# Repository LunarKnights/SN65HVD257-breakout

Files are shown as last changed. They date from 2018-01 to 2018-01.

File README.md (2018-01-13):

# Jetson CAN interface board
This board may be used to gain access to the CAN buses on the Jetson TX2 board, which aren't exposed on the carrier board we're currently using.
It mates in between the carrier board and the Jetson TX2, passing through all the connections, but tapping some lines off of the CAN pins and power supply to use in the SN65HVD256D CAN transceivers.
The CAN transceivers act essentially like level shifters, converting from the 3.3 V signals on the CAN RX/TX pins on the Jetson TX2 into the 5 V differential signal used in CAN.

`bom.xls` contains an Excel ordering list that should be usable at Mouser to reorder all the components except for the Samtec connectors.
Those need to be ordered off of the Samtec website, using the exact part names from the design.

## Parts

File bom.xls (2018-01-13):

SHOPPING CART
This is not an invoice
13-Jan-18 11:54:24
 | Mouser # | Mfr. # | Manufacturer | Customer # | Description | RoHS | Lifecycle | Order Qty. | Price (USD) | Ext.: (USD)
1 | 863-NCP7805TG | NCP7805TG | ON Semiconductor |  | Linear Voltage Regulators 1A LDO | RoHS Compliant |  | 5 | $0.43 | $2.15
2 | 538-39532-0002 | 39532-0002 | Molex |  | Pluggable Terminal Blocks 5.08MM EURO HEADER R EADER RA OE BLK 2CKT | RoHS Compliant |  | 5 | $0.50 | $2.50
3 | 538-39530-0002 | 39530-0002 | Molex |  | Pluggable Terminal Blocks 5.08MM EURO PLUG RA BLK 2CKT | RoHS Compliant |  | 5 | $1.25 | $6.25
4 | 595-SN65HVD256DR | SN65HVD256DR | Texas Instruments |  | CAN Interface IC CAN Transceiver w/ Fast Loop Times | RoHS Compliant |  | 5 | $2.15 | $10.75
5 | 710-885012207011 | 885012207011 | Wurth Electronics |  | Multilayer Ceramic Capacitors MLCC - SMD/SMT WCAP-CSGP 10000pF 0805 10% 10V MLCC | RoHS Compliant |  | 10 | $0.07 | $0.70
6 | 80-C1206C104K5R | C1206C104K5RACTU | KEMET |  | Multilayer Ceramic Capacitors MLCC - SMD/SMT 50volts 0.1uF X7R 10% | RoHS Compliant |  | 10 | $0.042 | $0.42
7 | 81-BLM21AG221BH1D | BLM21AG221BH1D | Murata |  | Ferrite Beads 0805 220oHMS 900mA DRC=0.12ohm AEC-Q200 | RoHS Compliant | New Product | 10 | $0.105 | $1.05
8 | 81-BLM31KN102SH1L | BLM31KN102SH1L | Murata |  | Ferrite Beads 1206 1000ohms 2A AECQ200 Pwrtrain/Saf | RoHS Compliant | New Product | 10 | $0.188 | $1.88
9 | 998-MIC5365-3.3YD5TR | MIC5365-3.3YD5-TR | Microchip |  | LDO Voltage Regulators | RoHS Compliant |  | 10 | $0.16 | $1.60
10 | 963-UMK316BBJ106ML-T | UMK316BBJ106ML-T | Taiyo Yuden |  | Multilayer Ceramic Capacitors MLCC - SMD/SMT 10uF 50V X5R +/-20% 1206 Gen Purp | RoHS Compliant |  | 10 | $0.269 | $2.69
11 | 595-UA78M05IDCYR | UA78M05IDCYR | Texas Instruments |  | Linear Voltage Regulators 5V 500mA Fixed Pos Voltage Regulator | RoHS Compliant |  | 10 | $0.512 | $5.12
By submitting your order you agree to these terms and conditions. (https://www.mouser.com/saleterms) |  |  |  |  |  |  |  |  | Merchandise Total: | $35.11
Prices are reflected at the date and time shown. |  |  |  |  |  |  |  |  | Shipping Charge: | Estimate

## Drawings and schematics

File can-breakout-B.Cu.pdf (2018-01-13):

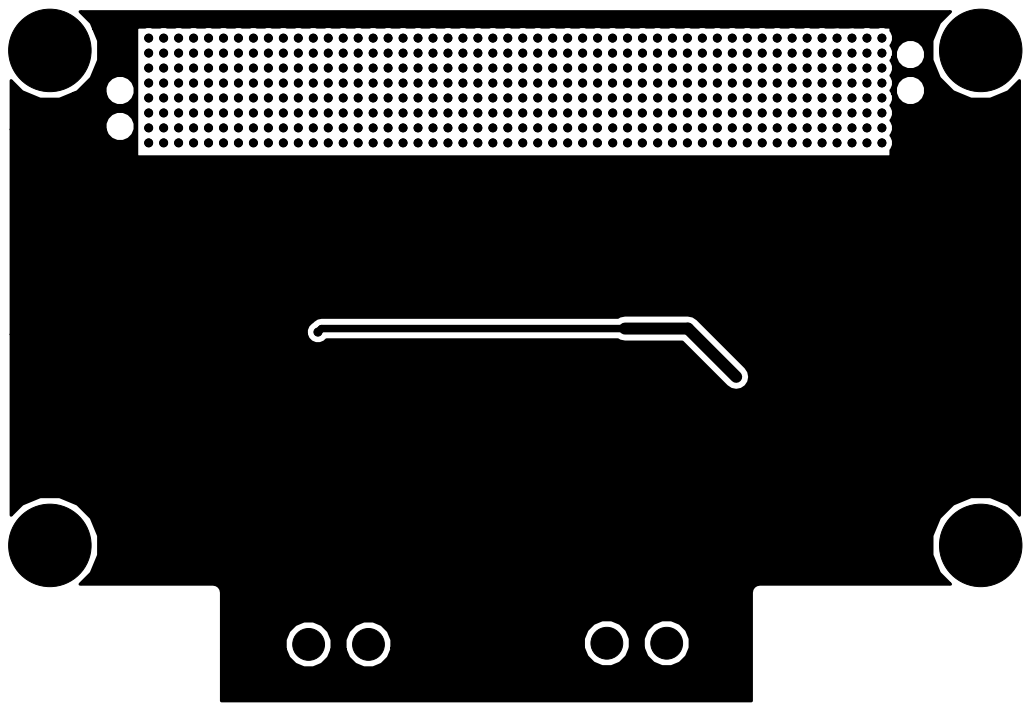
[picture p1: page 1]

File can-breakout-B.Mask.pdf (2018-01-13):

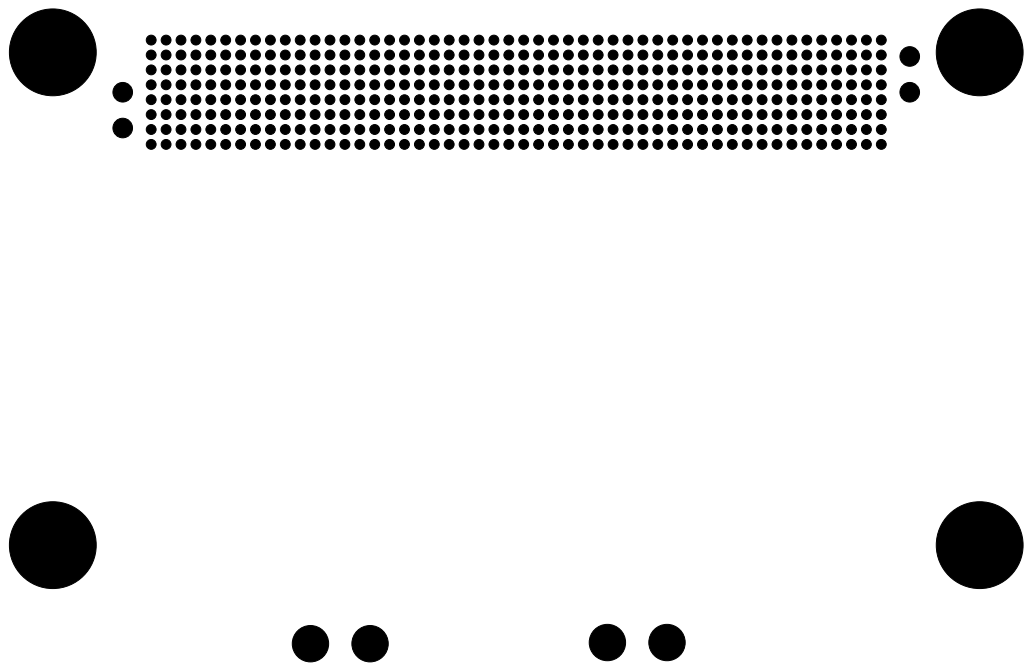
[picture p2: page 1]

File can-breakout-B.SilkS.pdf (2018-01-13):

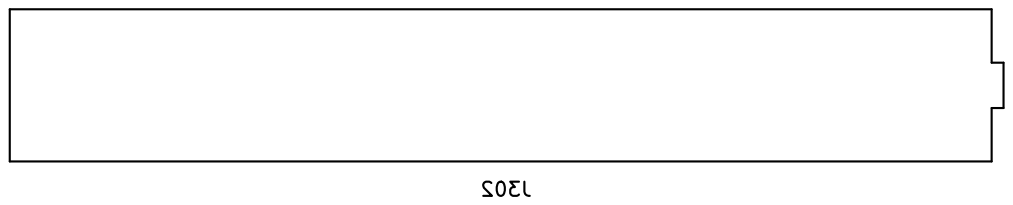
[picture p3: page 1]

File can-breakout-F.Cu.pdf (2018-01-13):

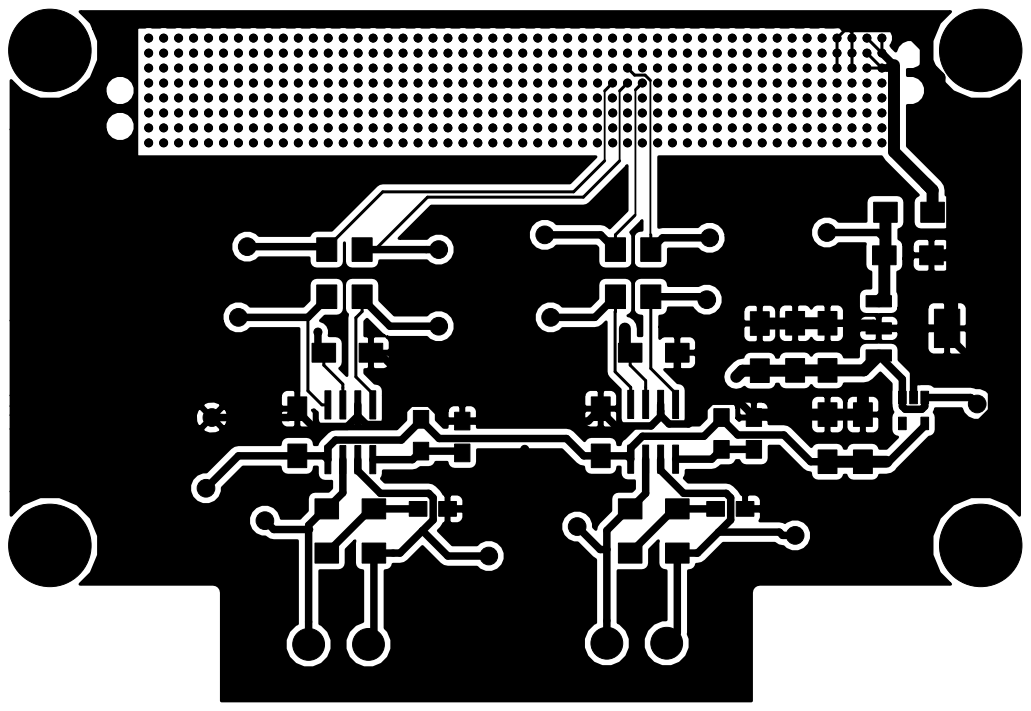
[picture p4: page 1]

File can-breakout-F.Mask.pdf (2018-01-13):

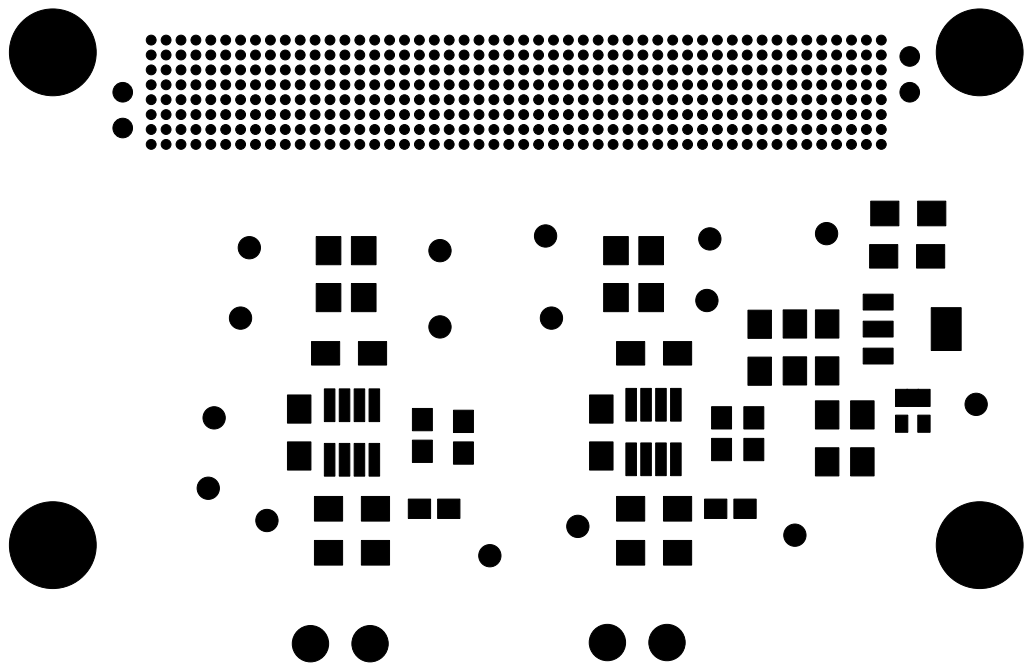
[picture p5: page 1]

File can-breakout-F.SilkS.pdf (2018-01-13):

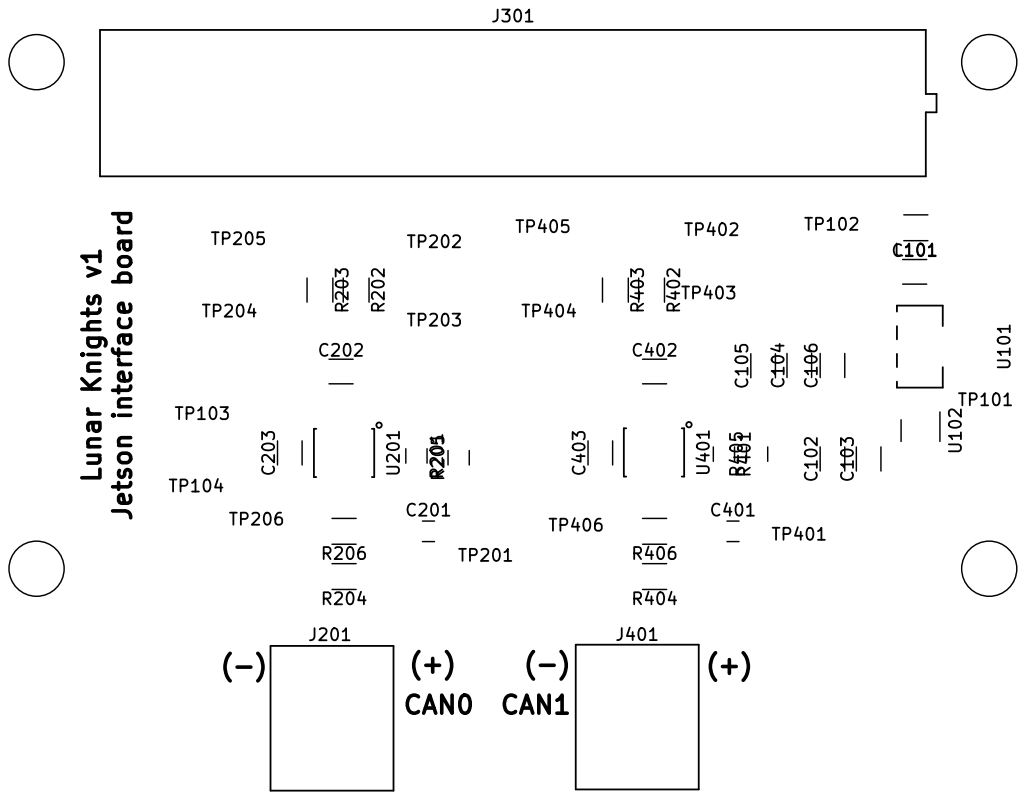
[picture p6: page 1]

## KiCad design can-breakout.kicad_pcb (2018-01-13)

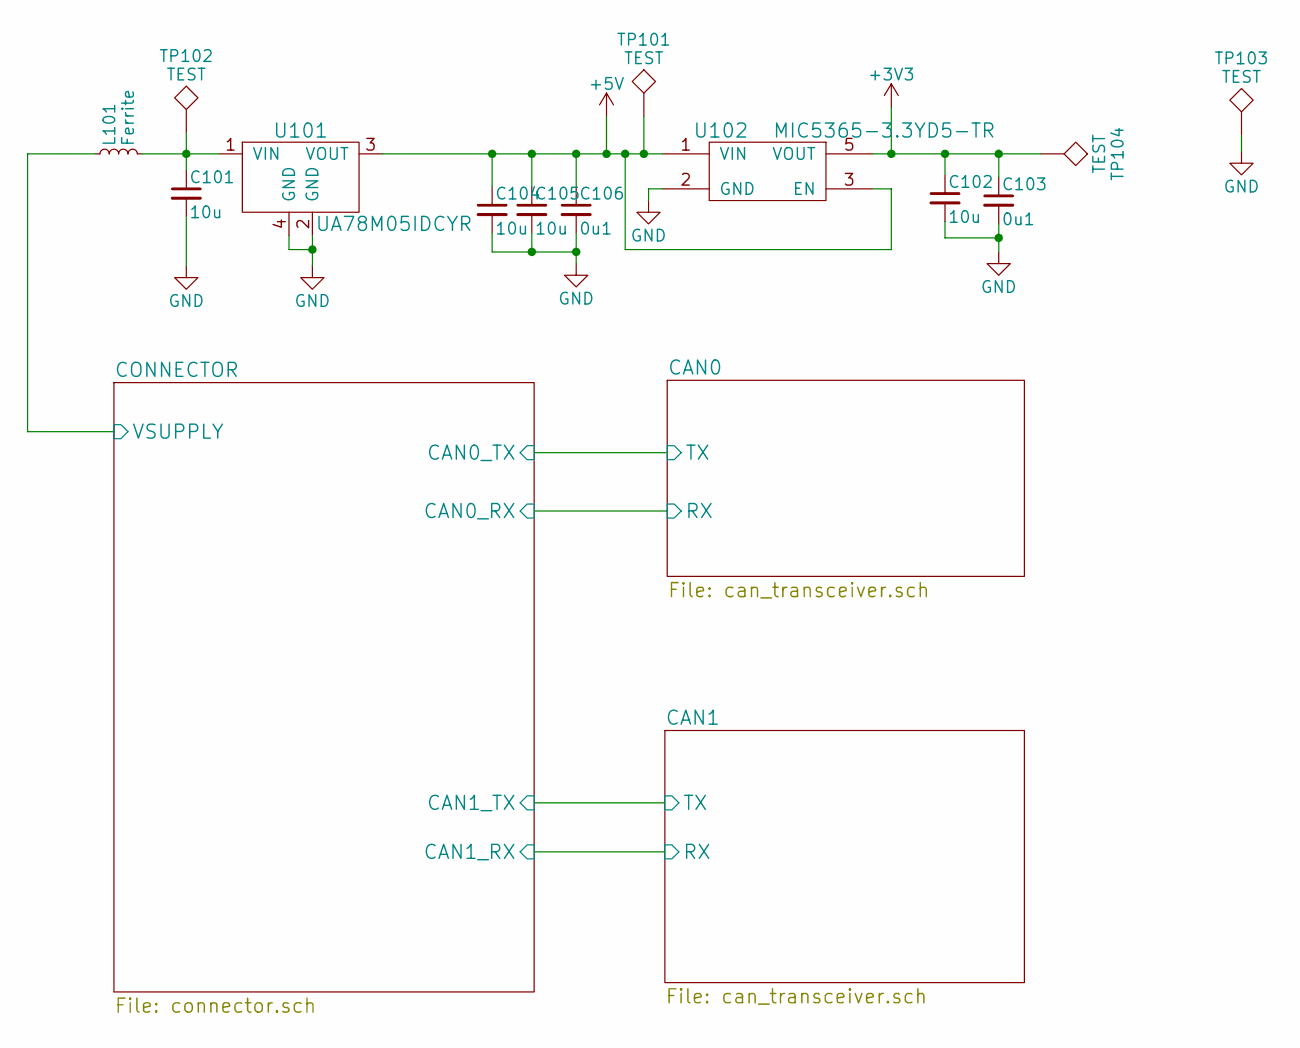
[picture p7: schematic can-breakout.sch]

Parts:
C101, C102, C104, C105: 10u; C_1206_HandSoldering
C103, C106: 0u1; C_1206_HandSoldering
L101: Ferrite; R_1206_HandSoldering
TP101, TP102, TP103, TP104: TEST; Measurement_Point_Round-SMD-Pad_Small
U101: UA78M05IDCYR; TI_SOT-223-4
U102: MIC5365-3.3YD5-TR; SOT-23-5

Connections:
+3V3: C102.1, C103.1, TP104.1, U102.5 (VOUT); also elsewhere on the board
+5V: C104.1, C105.1, C106.1, TP101.1, U101.3 (VOUT), U102.1 (VIN), U102.3 (EN); also elsewhere on the board
/CONNECTOR/VSUPPLY: L101.1; also elsewhere on the board
GND: C101.2, C102.2, C103.2, C104.2, C105.2, C106.2, TP103.1, U101.2 (GND), U101.4 (GND), U102.2 (GND); also elsewhere on the board
unnamed: C101.1, L101.2, TP102.1, U101.1 (VIN)

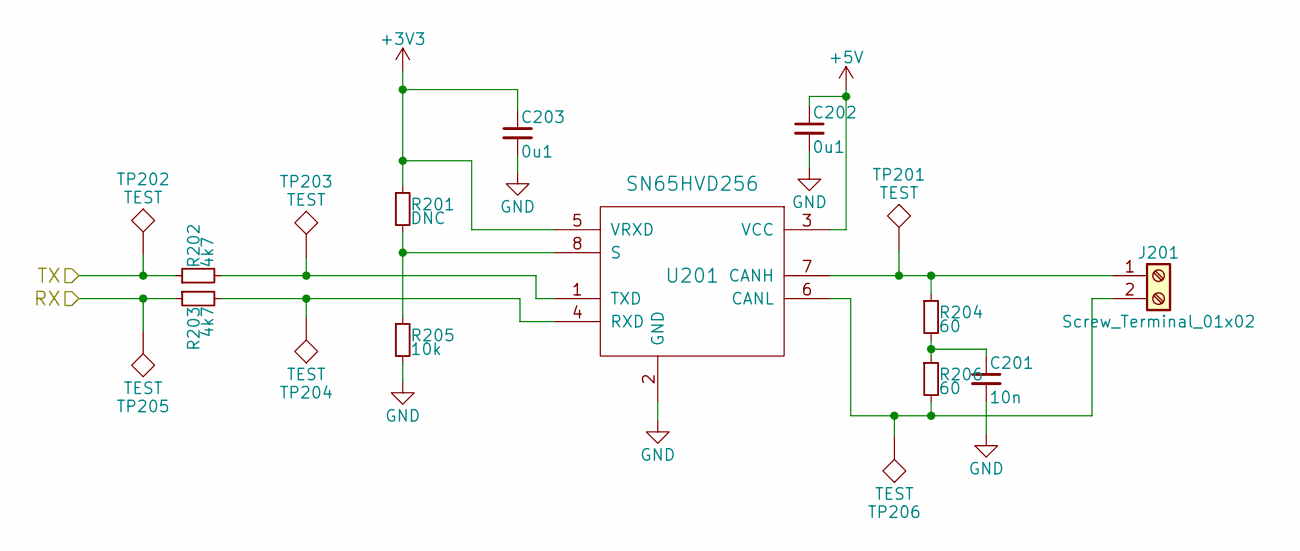
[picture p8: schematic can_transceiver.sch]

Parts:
C201: 10n; C_0805_HandSoldering
C202, C203: 0u1; C_1206_HandSoldering
J201: Screw_Terminal_01x02; 39532-0002
R201: DNC; R_0805_HandSoldering
R202, R203: 4k7; R_1206_HandSoldering
R204, R206: 60; R_1206_HandSoldering
R205: 10k; R_0805_HandSoldering
TP201, TP202, TP203, TP204, TP205, TP206: TEST; Measurement_Point_Round-SMD-Pad_Small
U201: SN65HVD256; TI_SOIC8

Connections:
+3V3: C203.1, R201.1, U201.5 (VRXD); also elsewhere on the board
+5V: C202.1, U201.3 (VCC); also elsewhere on the board
/CONNECTOR/CAN0_RX: R203.1, TP205.1; also elsewhere on the board
/CONNECTOR/CAN0_TX: R202.1, TP202.1; also elsewhere on the board
GND: C201.2, C202.2, C203.2, R205.2, U201.2 (GND); also elsewhere on the board
unnamed: C201.1, R204.2, R206.1
unnamed: J201.1, R204.1, TP201.1, U201.7 (CANH)
unnamed: J201.2, R206.2, TP206.1, U201.6 (CANL)
unnamed: R201.2, R205.1, U201.8 (S)
unnamed: R202.2, TP203.1, U201.1 (TXD)
unnamed: R203.2, TP204.1, U201.4 (RXD)

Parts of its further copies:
C401: 10n; C_0805_HandSoldering
C402, C403: 0u1; C_1206_HandSoldering
J401: Screw_Terminal_01x02; 39532-0002
R401: DNC; R_0805_HandSoldering
R402, R403: 4k7; R_1206_HandSoldering
R404, R406: 60; R_1206_HandSoldering
R405: 10k; R_0805_HandSoldering
TP401, TP402, TP403, TP404, TP405, TP406: TEST; Measurement_Point_Round-SMD-Pad_Small
U401: SN65HVD256; TI_SOIC8

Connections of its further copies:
+3V3: C403.1, R401.1, U401.5 (VRXD); also elsewhere on the board
+5V: C402.1, U401.3 (VCC); also elsewhere on the board
/CONNECTOR/CAN1_RX: R403.1, TP405.1; also elsewhere on the board
/CONNECTOR/CAN1_TX: R402.1, TP402.1; also elsewhere on the board
GND: C401.2, C402.2, C403.2, R405.2, U401.2 (GND); also elsewhere on the board
unnamed: C401.1, R404.2, R406.1
unnamed: J401.1, R404.1, TP401.1, U401.7 (CANH)
unnamed: J401.2, R406.2, TP406.1, U401.6 (CANL)
unnamed: R401.2, R405.1, U401.8 (S)
unnamed: R402.2, TP403.1, U401.1 (TXD)
unnamed: R403.2, TP404.1, U401.4 (RXD)

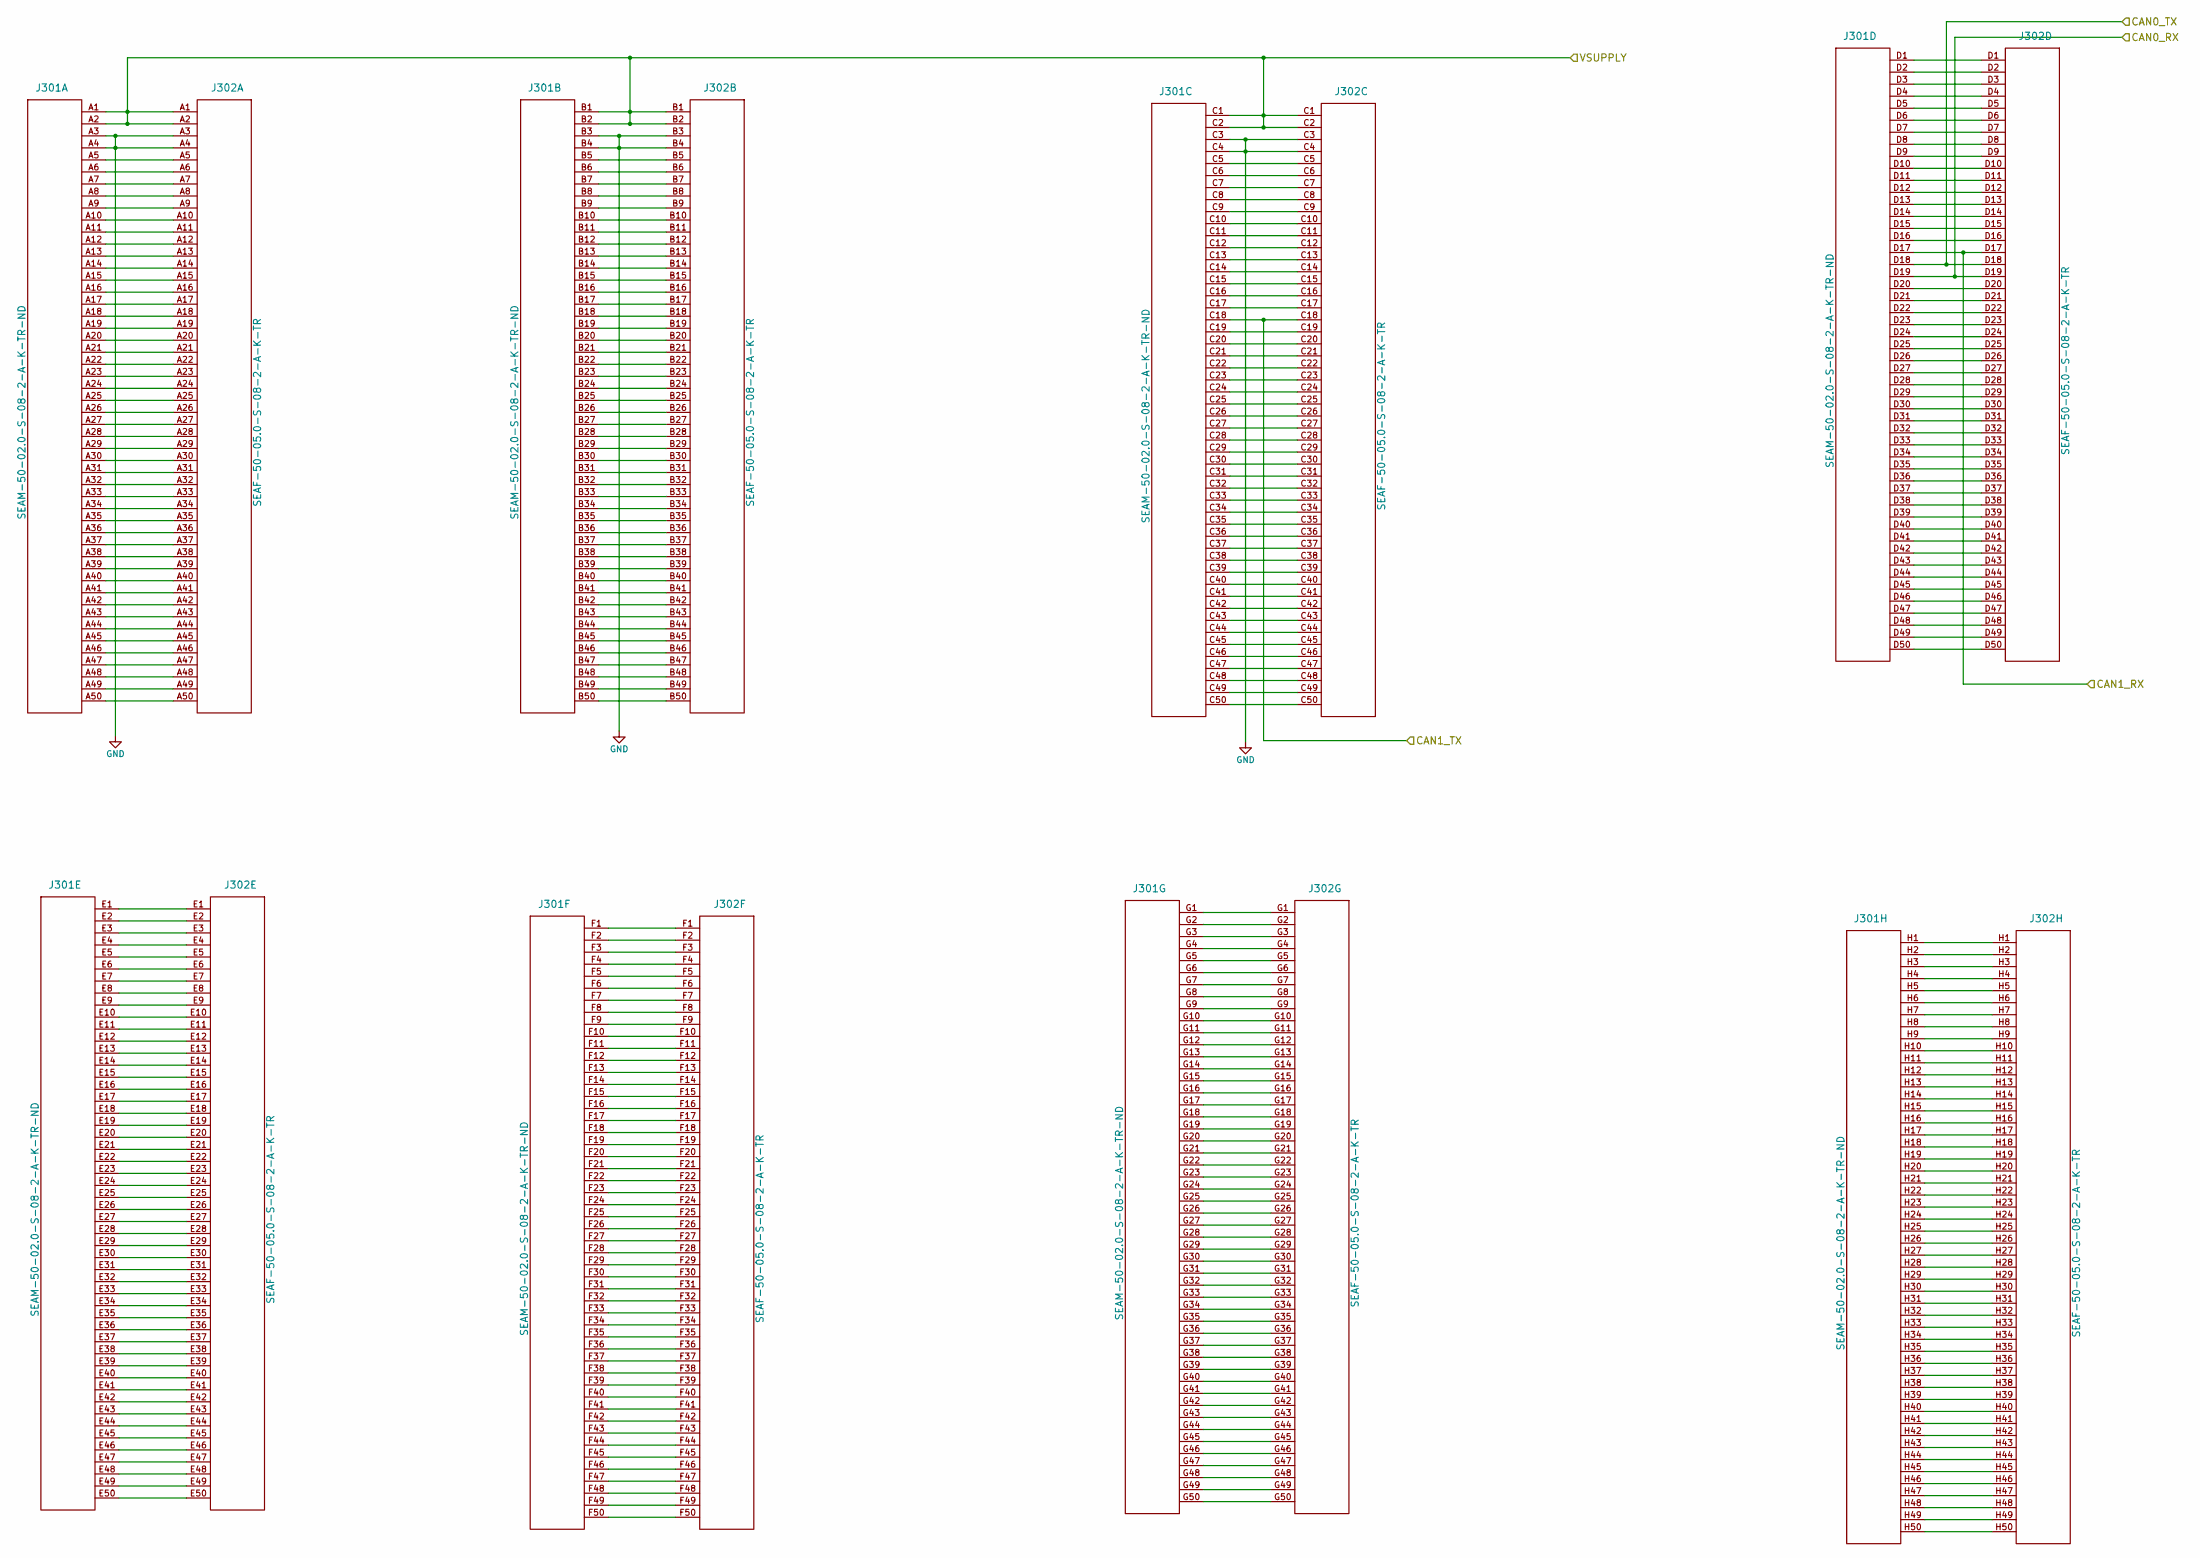
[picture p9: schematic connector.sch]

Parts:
J301: SEAM-50-02.0-S-08-2-A-K-TR-ND; SEAM-50-02.0-S-08-2-A-K-TR
J302: SEAF-50-05.0-S-08-2-A-K-TR

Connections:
/CONNECTOR/CAN0_RX: J301.D19, J302.D19; also elsewhere on the board
/CONNECTOR/CAN0_TX: J301.D18, J302.D18; also elsewhere on the board
/CONNECTOR/CAN1_RX: J301.D17, J302.D17; also elsewhere on the board
/CONNECTOR/CAN1_TX: J301.C18, J302.C18; also elsewhere on the board
/CONNECTOR/VSUPPLY: J301.A1, J301.A2, J301.B1, J301.B2, J301.C1, J301.C2, J302.A1, J302.A2, J302.B1, J302.B2, J302.C1, J302.C2; also elsewhere on the board
GND: J301.A3, J301.A4, J301.B3, J301.B4, J301.C3, J301.C4, J302.A3, J302.A4, J302.B3, J302.B4, J302.C3, J302.C4; also elsewhere on the board
unnamed: J301.A5, J302.A5
unnamed: J301.A6, J302.A6
unnamed: J301.A7, J302.A7
unnamed: J301.A8, J302.A8
unnamed: J301.A9, J302.A9
unnamed: J301.A10, J302.A10
unnamed: J301.A11, J302.A11
unnamed: J301.A12, J302.A12
unnamed: J301.A13, J302.A13
unnamed: J301.A14, J302.A14
unnamed: J301.A15, J302.A15
unnamed: J301.A16, J302.A16
unnamed: J301.A17, J302.A17
unnamed: J301.A18, J302.A18
unnamed: J301.A19, J302.A19
unnamed: J301.A20, J302.A20
unnamed: J301.A21, J302.A21
unnamed: J301.A22, J302.A22
unnamed: J301.A23, J302.A23
unnamed: J301.A24, J302.A24
unnamed: J301.A25, J302.A25
unnamed: J301.A26, J302.A26
unnamed: J301.A27, J302.A27
unnamed: J301.A28, J302.A28
unnamed: J301.A29, J302.A29
unnamed: J301.A30, J302.A30
unnamed: J301.A31, J302.A31
unnamed: J301.A32, J302.A32
unnamed: J301.A33, J302.A33
unnamed: J301.A34, J302.A34
unnamed: J301.A35, J302.A35
unnamed: J301.A36, J302.A36
unnamed: J301.A37, J302.A37
unnamed: J301.A38, J302.A38
unnamed: J301.A39, J302.A39
unnamed: J301.A40, J302.A40
unnamed: J301.A41, J302.A41
unnamed: J301.A42, J302.A42
unnamed: J301.A43, J302.A43
unnamed: J301.A44, J302.A44
unnamed: J301.A45, J302.A45
unnamed: J301.A46, J302.A46
unnamed: J301.A47, J302.A47
unnamed: J301.A48, J302.A48
unnamed: J301.A49, J302.A49
unnamed: J301.A50, J302.A50
unnamed: J301.B5, J302.B5
unnamed: J301.B6, J302.B6
unnamed: J301.B7, J302.B7
unnamed: J301.B8, J302.B8
unnamed: J301.B9, J302.B9
unnamed: J301.B10, J302.B10
unnamed: J301.B11, J302.B11
unnamed: J301.B12, J302.B12
unnamed: J301.B13, J302.B13
unnamed: J301.B14, J302.B14
unnamed: J301.B15, J302.B15
unnamed: J301.B16, J302.B16
unnamed: J301.B17, J302.B17
unnamed: J301.B18, J302.B18
unnamed: J301.B19, J302.B19
unnamed: J301.B20, J302.B20
unnamed: J301.B21, J302.B21
unnamed: J301.B22, J302.B22
unnamed: J301.B23, J302.B23
unnamed: J301.B24, J302.B24
unnamed: J301.B25, J302.B25
unnamed: J301.B26, J302.B26
unnamed: J301.B27, J302.B27
unnamed: J301.B28, J302.B28
unnamed: J301.B29, J302.B29
unnamed: J301.B30, J302.B30
unnamed: J301.B31, J302.B31
unnamed: J301.B32, J302.B32
unnamed: J301.B33, J302.B33
unnamed: J301.B34, J302.B34
unnamed: J301.B35, J302.B35
unnamed: J301.B36, J302.B36
unnamed: J301.B37, J302.B37
unnamed: J301.B38, J302.B38
unnamed: J301.B39, J302.B39
unnamed: J301.B40, J302.B40
unnamed: J301.B41, J302.B41
unnamed: J301.B42, J302.B42
unnamed: J301.B43, J302.B43
unnamed: J301.B44, J302.B44
unnamed: J301.B45, J302.B45
unnamed: J301.B46, J302.B46
unnamed: J301.B47, J302.B47
unnamed: J301.B48, J302.B48
unnamed: J301.B49, J302.B49
unnamed: J301.B50, J302.B50
unnamed: J301.C5, J302.C5
unnamed: J301.C6, J302.C6
unnamed: J301.C7, J302.C7
unnamed: J301.C8, J302.C8
unnamed: J301.C9, J302.C9
unnamed: J301.C10, J302.C10
unnamed: J301.C11, J302.C11
unnamed: J301.C12, J302.C12
unnamed: J301.C13, J302.C13
unnamed: J301.C14, J302.C14
unnamed: J301.C15, J302.C15
unnamed: J301.C16, J302.C16
unnamed: J301.C17, J302.C17
unnamed: J301.C19, J302.C19
unnamed: J301.C20, J302.C20
unnamed: J301.C21, J302.C21
unnamed: J301.C22, J302.C22
unnamed: J301.C23, J302.C23
unnamed: J301.C24, J302.C24
unnamed: J301.C25, J302.C25
unnamed: J301.C26, J302.C26
unnamed: J301.C27, J302.C27
unnamed: J301.C28, J302.C28
unnamed: J301.C29, J302.C29
unnamed: J301.C30, J302.C30
unnamed: J301.C31, J302.C31
unnamed: J301.C32, J302.C32
unnamed: J301.C33, J302.C33
unnamed: J301.C34, J302.C34
unnamed: J301.C35, J302.C35
unnamed: J301.C36, J302.C36
unnamed: J301.C37, J302.C37
unnamed: J301.C38, J302.C38
unnamed: J301.C39, J302.C39
unnamed: J301.C40, J302.C40
unnamed: J301.C41, J302.C41
unnamed: J301.C42, J302.C42
unnamed: J301.C43, J302.C43
unnamed: J301.C44, J302.C44
unnamed: J301.C45, J302.C45
unnamed: J301.C46, J302.C46
unnamed: J301.C47, J302.C47
unnamed: J301.C48, J302.C48
unnamed: J301.C49, J302.C49
unnamed: J301.C50, J302.C50
unnamed: J301.D1, J302.D1
unnamed: J301.D2, J302.D2
unnamed: J301.D3, J302.D3
unnamed: J301.D4, J302.D4
unnamed: J301.D5, J302.D5
unnamed: J301.D6, J302.D6
unnamed: J301.D7, J302.D7
unnamed: J301.D8, J302.D8
unnamed: J301.D9, J302.D9
unnamed: J301.D10, J302.D10
unnamed: J301.D11, J302.D11
unnamed: J301.D12, J302.D12
unnamed: J301.D13, J302.D13
unnamed: J301.D14, J302.D14
unnamed: J301.D15, J302.D15
unnamed: J301.D16, J302.D16
unnamed: J301.D20, J302.D20
unnamed: J301.D21, J302.D21
unnamed: J301.D22, J302.D22
unnamed: J301.D23, J302.D23
unnamed: J301.D24, J302.D24
unnamed: J301.D25, J302.D25
unnamed: J301.D26, J302.D26
unnamed: J301.D27, J302.D27
unnamed: J301.D28, J302.D28
unnamed: J301.D29, J302.D29
unnamed: J301.D30, J302.D30
unnamed: J301.D31, J302.D31
unnamed: J301.D32, J302.D32
unnamed: J301.D33, J302.D33
unnamed: J301.D34, J302.D34
unnamed: J301.D35, J302.D35
unnamed: J301.D36, J302.D36
unnamed: J301.D37, J302.D37
unnamed: J301.D38, J302.D38
unnamed: J301.D39, J302.D39
unnamed: J301.D40, J302.D40
unnamed: J301.D41, J302.D41
unnamed: J301.D42, J302.D42
unnamed: J301.D43, J302.D43
unnamed: J301.D44, J302.D44
unnamed: J301.D45, J302.D45
unnamed: J301.D46, J302.D46
unnamed: J301.D47, J302.D47
unnamed: J301.D48, J302.D48
unnamed: J301.D49, J302.D49
unnamed: J301.D50, J302.D50
unnamed: J301.E1, J302.E1
unnamed: J301.E2, J302.E2
unnamed: J301.E3, J302.E3
unnamed: J301.E4, J302.E4
unnamed: J301.E5, J302.E5
unnamed: J301.E6, J302.E6
unnamed: J301.E7, J302.E7
unnamed: J301.E8, J302.E8
unnamed: J301.E9, J302.E9
unnamed: J301.E10, J302.E10
unnamed: J301.E11, J302.E11
unnamed: J301.E12, J302.E12
unnamed: J301.E13, J302.E13
unnamed: J301.E14, J302.E14
unnamed: J301.E15, J302.E15
unnamed: J301.E16, J302.E16
unnamed: J301.E17, J302.E17
unnamed: J301.E18, J302.E18
unnamed: J301.E19, J302.E19
unnamed: J301.E20, J302.E20
unnamed: J301.E21, J302.E21
unnamed: J301.E22, J302.E22
unnamed: J301.E23, J302.E23
unnamed: J301.E24, J302.E24
unnamed: J301.E25, J302.E25
unnamed: J301.E26, J302.E26
unnamed: J301.E27, J302.E27
unnamed: J301.E28, J302.E28
unnamed: J301.E29, J302.E29
unnamed: J301.E30, J302.E30
unnamed: J301.E31, J302.E31
unnamed: J301.E32, J302.E32
unnamed: J301.E33, J302.E33
unnamed: J301.E34, J302.E34
unnamed: J301.E35, J302.E35
unnamed: J301.E36, J302.E36
unnamed: J301.E37, J302.E37
unnamed: J301.E38, J302.E38
unnamed: J301.E39, J302.E39
unnamed: J301.E40, J302.E40
unnamed: J301.E41, J302.E41
unnamed: J301.E42, J302.E42
unnamed: J301.E43, J302.E43
unnamed: J301.E44, J302.E44
unnamed: J301.E45, J302.E45
unnamed: J301.E46, J302.E46
unnamed: J301.E47, J302.E47
unnamed: J301.E48, J302.E48
unnamed: J301.E49, J302.E49
unnamed: J301.E50, J302.E50
unnamed: J301.F1, J302.F1
unnamed: J301.F2, J302.F2
unnamed: J301.F3, J302.F3
unnamed: J301.F4, J302.F4
unnamed: J301.F5, J302.F5
unnamed: J301.F6, J302.F6
unnamed: J301.F7, J302.F7
unnamed: J301.F8, J302.F8
unnamed: J301.F9, J302.F9
unnamed: J301.F10, J302.F10
unnamed: J301.F11, J302.F11
unnamed: J301.F12, J302.F12
unnamed: J301.F13, J302.F13
unnamed: J301.F14, J302.F14
unnamed: J301.F15, J302.F15
unnamed: J301.F16, J302.F16
unnamed: J301.F17, J302.F17
unnamed: J301.F18, J302.F18
unnamed: J301.F19, J302.F19
unnamed: J301.F20, J302.F20
unnamed: J301.F21, J302.F21
unnamed: J301.F22, J302.F22
unnamed: J301.F23, J302.F23
unnamed: J301.F24, J302.F24
unnamed: J301.F25, J302.F25
unnamed: J301.F26, J302.F26
unnamed: J301.F27, J302.F27
unnamed: J301.F28, J302.F28
unnamed: J301.F29, J302.F29
unnamed: J301.F30, J302.F30
unnamed: J301.F31, J302.F31
unnamed: J301.F32, J302.F32
unnamed: J301.F33, J302.F33
unnamed: J301.F34, J302.F34
unnamed: J301.F35, J302.F35
unnamed: J301.F36, J302.F36
unnamed: J301.F37, J302.F37
unnamed: J301.F38, J302.F38
unnamed: J301.F39, J302.F39
unnamed: J301.F40, J302.F40
unnamed: J301.F41, J302.F41
unnamed: J301.F42, J302.F42
unnamed: J301.F43, J302.F43
unnamed: J301.F44, J302.F44
unnamed: J301.F45, J302.F45
unnamed: J301.F46, J302.F46
unnamed: J301.F47, J302.F47
unnamed: J301.F48, J302.F48
unnamed: J301.F49, J302.F49
unnamed: J301.F50, J302.F50
unnamed: J301.G1, J302.G1
unnamed: J301.G2, J302.G2
unnamed: J301.G3, J302.G3
unnamed: J301.G4, J302.G4
unnamed: J301.G5, J302.G5
unnamed: J301.G6, J302.G6
unnamed: J301.G7, J302.G7
unnamed: J301.G8, J302.G8
unnamed: J301.G9, J302.G9
unnamed: J301.G10, J302.G10
unnamed: J301.G11, J302.G11
unnamed: J301.G12, J302.G12
unnamed: J301.G13, J302.G13
unnamed: J301.G14, J302.G14
unnamed: J301.G15, J302.G15
unnamed: J301.G16, J302.G16
unnamed: J301.G17, J302.G17
unnamed: J301.G18, J302.G18
unnamed: J301.G19, J302.G19
unnamed: J301.G20, J302.G20
unnamed: J301.G21, J302.G21
unnamed: J301.G22, J302.G22
unnamed: J301.G23, J302.G23
unnamed: J301.G24, J302.G24
unnamed: J301.G25, J302.G25
unnamed: J301.G26, J302.G26
unnamed: J301.G27, J302.G27
unnamed: J301.G28, J302.G28
unnamed: J301.G29, J302.G29
unnamed: J301.G30, J302.G30
unnamed: J301.G31, J302.G31
unnamed: J301.G32, J302.G32
unnamed: J301.G33, J302.G33
unnamed: J301.G34, J302.G34
unnamed: J301.G35, J302.G35
unnamed: J301.G36, J302.G36
unnamed: J301.G37, J302.G37
unnamed: J301.G38, J302.G38
unnamed: J301.G39, J302.G39
unnamed: J301.G40, J302.G40
unnamed: J301.G41, J302.G41
unnamed: J301.G42, J302.G42
unnamed: J301.G43, J302.G43
unnamed: J301.G44, J302.G44
unnamed: J301.G45, J302.G45
unnamed: J301.G46, J302.G46
unnamed: J301.G47, J302.G47
unnamed: J301.G48, J302.G48
unnamed: J301.G49, J302.G49
unnamed: J301.G50, J302.G50
unnamed: J301.H1, J302.H1
unnamed: J301.H2, J302.H2
unnamed: J301.H3, J302.H3
unnamed: J301.H4, J302.H4
unnamed: J301.H5, J302.H5
unnamed: J301.H6, J302.H6
unnamed: J301.H7, J302.H7
unnamed: J301.H8, J302.H8
unnamed: J301.H9, J302.H9
unnamed: J301.H10, J302.H10
unnamed: J301.H11, J302.H11
unnamed: J301.H12, J302.H12
unnamed: J301.H13, J302.H13
unnamed: J301.H14, J302.H14
unnamed: J301.H15, J302.H15
unnamed: J301.H16, J302.H16
unnamed: J301.H17, J302.H17
unnamed: J301.H18, J302.H18
unnamed: J301.H19, J302.H19
unnamed: J301.H20, J302.H20
unnamed: J301.H21, J302.H21
unnamed: J301.H22, J302.H22
unnamed: J301.H23, J302.H23
unnamed: J301.H24, J302.H24
unnamed: J301.H25, J302.H25
unnamed: J301.H26, J302.H26
unnamed: J301.H27, J302.H27
unnamed: J301.H28, J302.H28
unnamed: J301.H29, J302.H29
unnamed: J301.H30, J302.H30
unnamed: J301.H31, J302.H31
unnamed: J301.H32, J302.H32
unnamed: J301.H33, J302.H33
unnamed: J301.H34, J302.H34
unnamed: J301.H35, J302.H35
unnamed: J301.H36, J302.H36
unnamed: J301.H37, J302.H37
unnamed: J301.H38, J302.H38
unnamed: J301.H39, J302.H39
unnamed: J301.H40, J302.H40
unnamed: J301.H41, J302.H41
unnamed: J301.H42, J302.H42
unnamed: J301.H43, J302.H43
unnamed: J301.H44, J302.H44
unnamed: J301.H45, J302.H45
unnamed: J301.H46, J302.H46
unnamed: J301.H47, J302.H47
unnamed: J301.H48, J302.H48
unnamed: J301.H49, J302.H49
unnamed: J301.H50, J302.H50

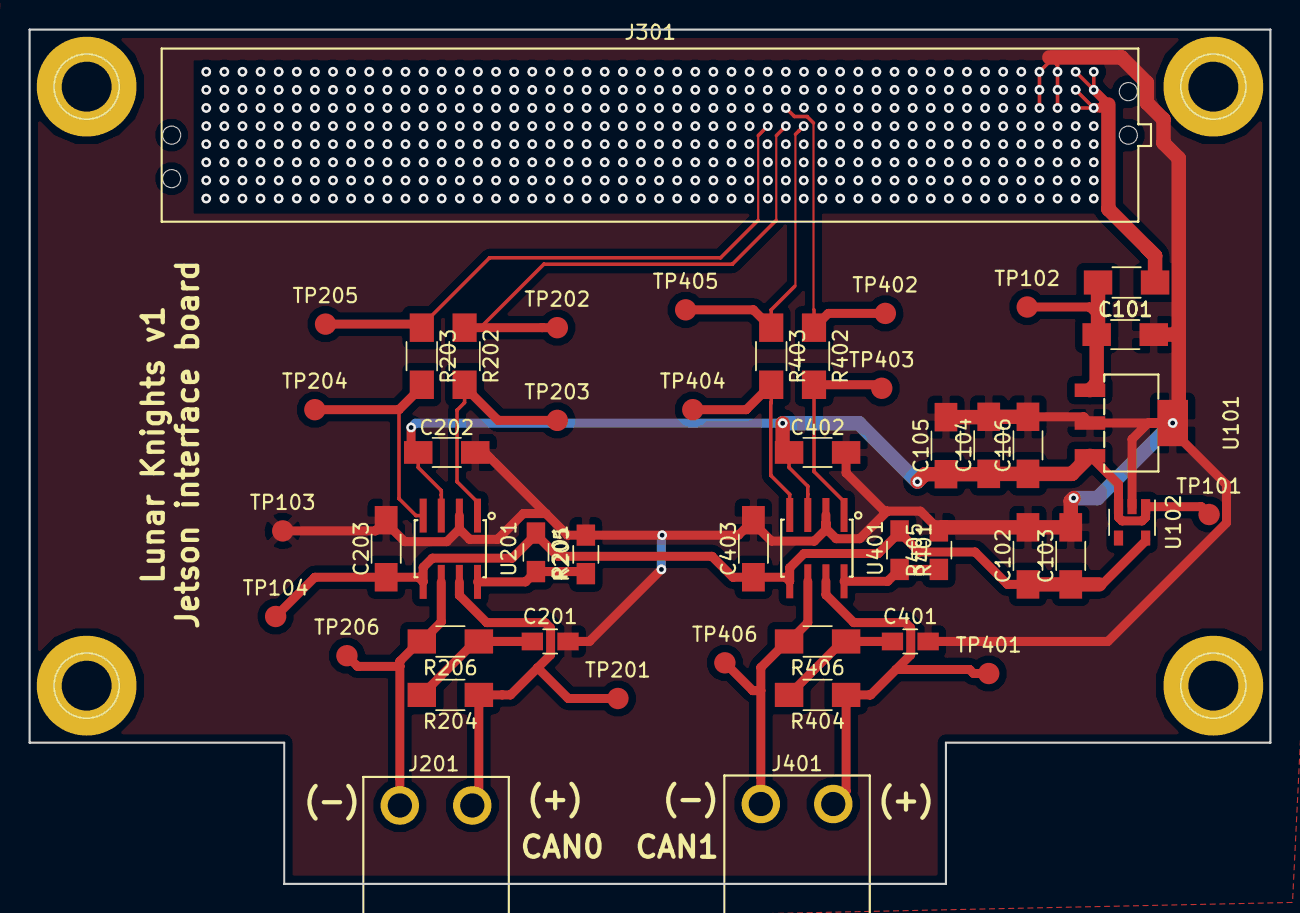
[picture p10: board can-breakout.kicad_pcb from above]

Board: 2 copper layers, 87.0 x 59.9 mm, 49 parts (1 on the bottom side), 405 nets.

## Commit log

2017-11-18 Save work for attendance check
    [can-breakout.kicad_pcb, can-breakout.sch]
2017-11-18 Add schematic PDF
2017-11-18 Start work on CAN layout
    [can-breakout.sch]
2017-11-18 Add datasheet for connector
2017-11-20 Start work on library part for SEAM connector
2017-11-20 Make library files for both connectors and wire them together
    [can-breakout.sch, can_transceiver.sch, connector.sch]
2017-11-20 python gen-seam-fp.py > breakout.pretty/SEAM-50-02.0-S-08-2-A-K-TR.kicad_mod; python gen-seaf-fp.py > breakout.pretty/SEAF-50-05.0-S-08-2-A-K-TR.kicad_mod
2017-11-20 Add vias and ground connections
    [can-breakout.kicad_pcb, can_transceiver.sch, connector.sch]
2017-11-20 Add hierarchial pins for CAN, TODO regen netlist
    [can-breakout.kicad_pcb, can_transceiver.sch, connector.sch]
2018-01-08 Add some protection diodes, connect most things up TODO add TVS diodes to CAN bus terinals
    [can-breakout.sch, can_transceiver.sch, connector.sch]
2018-01-09 Module outline added to PCB, first CAN bus added
    [can-breakout.kicad_pcb, can_transceiver.sch, connector.sch]
2018-01-10 Parts laid out, only routing left
    [can-breakout.kicad_pcb, can-breakout.sch, can_transceiver.sch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]
2018-01-13 Finish layout and generate Gerber files
    [can-breakout-B.Cu.gbr, can-breakout-B.Mask.gbr, can-breakout-B.SilkS.gbr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]
2018-01-13 Update PDFs
    [can-breakout.kicad_pcb]
2018-01-13 Add silkscreen markings
    [can-breakout.kicad_pcb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]
2018-01-13 Add Gerber zipfile and BOM; grep value can-breakout.net | sort | tr -d ' ' | cut -c 7- | rev | cut -c 2- | rev | uniq -c > bom
2018-01-13 Add orderable BOM and README
    [bom.xls]
